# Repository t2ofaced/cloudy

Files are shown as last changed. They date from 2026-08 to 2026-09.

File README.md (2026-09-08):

# cloudy

A custom designed 60% Keyboard this keyboard is the first diy / electronic project i made from scratch, so idea was simple i wanted a keyboard so i desigined one now hopefully i can assemble it too so this keyboard use nice nano v2 clone pro micro nrf52840 development board as it give me freedom of wireless kayboard this keyboard also includes 1 enoder and 1 display and it is fully rgb thanks to SK6812MINI-E SMD leds

---

## Schematics & Circuitry

Electornic part of this Proj is desigined in KiCad 10.0

  
<br>
this is main circuitry 

<br>

  
<br>
keyswitch matrix

<br>

  
<br>
rgb chain

---

## PCB Routing & 3D View

  
<br>
routed pcb

<br>

  
<br>
3d view

---

## CAD & Case Design

Mechanical part / CAD is desigined in 4 parts 2 each for Top plate and Base plate it is in 4 parts so  that it can be printed easily
Onshape - https://cad.onshape.com/documents/02d1cc1f7ec3e59871e42e68/w/e27206701595b8be94d4fc96/e/d50220b72c1b89afdf243eaf


  
<br>
keyboard with base plate

<br>



<br>
keyboard with top plate

---

## Final Assembly



<br>
fully assembled

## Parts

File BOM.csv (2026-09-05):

Part Name | Quantity | Link | Info | Price (USD)
JLCPCB PCB Manufacturing & Shipping | 1 | https://jlcpcb.com/ | PCB | $35
0.96 inch OLED Display | 1 | https://robu.in/product/0-96-oled-display-module/ | Oled dispay | $2.35
Tactile Switches | 7 sets | https://meckeys.com/shop/accessories/keyboard-accessories/key-switches/cherry-mx-rgb-switch/ | Switches | $26.3
NiceNanoV2 | 1 | https://robu.in/product/pro-micro-nrf52840-development-board-compatible-with-nicenano-v2-0/ | mcu | $8.67
1N4148 Diodes | 70 | https://quartzcomponents.com/products/1n4148-zener-diodel | diodes | $2.22
Custom Keycaps | 1 | https://curiositycaps.in/products/comic-mixed-light-cherry-1-7mm-thick-pbt-keycaps | keycaps | $24.35
SK6812MINI-E SMD | 72 | https://www.etstore.in/products/e9974?variant=48993209319675&country=IN&currency=INR | RGBB | $9.73
LiPo Battery | 1 | https://robu.in/product/400mah-pcm-protected-micro-li-po-battery/ | 3.7V 400mAh 1S | $2.32
Disc Capacitor | 70 | https://robu.in/product/100nf-50v-disc-capacitor/ | 100nf 50v | $1
Aluminum Electrolytic Capacitors | 5 | https://robu.in/product/ers1am471e12ot-aishi-470uf-10v-%C2%B120-plugind6-3xl12mm-aluminum-electrolytic-capacitors-leaded-rohs/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 | ERS1AM471E12OT-AISHI -470uF 10V ±20% Plugin | $.5
Resistor 470 Ohms | 10 | https://www.ktron.in/product/resistor-470-ohms-0-25w-5-th/ | Resistor 470 Ohms 0.25W 5% TH | $0.2
Male Connector | 3 | https://robu.in/product/ph-aw-2mm-2-pin-wafer-male-connector-through-hole-right-angle/ | PH-AW-2mm-2 pin | $0.2
Rotary Encoder with Switch | 1 | https://robu.in/product/hongyan-ec11h-7ce20p1zd20-rotary-encoder-with-push-button-switch-vertical-plug-in-5-pin/ | EC11H 7CE20P1ZD20 5-Pin | $0.7
Slide Switch | 5 | https://robu.in/product/slide-switch-ss-12d07-1p2t/ | SS-12D07 1P2T | $0.2
Tactile Switch | 5 | https://robu.in/product/ws-a06-4-3-waterproof-tact-switch-4-pin6x6x4-3/ | 6x6x4.3mm 4 Pin | $0.2
Stabilizers | 5 | https://stackskb.com/store/durock-clear-screw-in-stabilizers-v2 | 4+1 set | $16.93
TOTAL |  |  |  | ~ $131

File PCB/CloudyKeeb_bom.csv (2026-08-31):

Designator | Footprint | Quantity | Value | LCSC Part #
C1, C10, C11, C12, C13, C14, C15, C16, C17, C18, C19, C2, C20, C21, C22, C23, C24, C25, C26, C27, C28, C29, C3, C30, C31, C32, C33, C34, C35, C36, C37, C38, C39, C4, C40, C41, C42, C43, C44, C45, C46, C47, C48, C49, C5, C50, C51, C52, C53, C54, C55, C56, C57, C58, C59, C6, C60, C61, C7, C8, C9 | C_Disc_D3.8mm_W2.6mm_P2.50mm | 61 | C
C62 | CP_Radial_D6.3mm_P2.50mm | 1 | C_Polarized_US
D100, D101, D102, D103, D104, D105, D106, D107, D108, D109, D110, D111, D112, D113, D114, D115, D116, D117, D118, D119, D120, D121, D122, D62, D63, D64, D65, D66, D67, D68, D69, D70, D71, D72, D73, D74, D75, D76, D77, D78, D79, D80, D81, D82, D83, D84, D85, D86, D87, D88, D89, D90, D91, D92, D93, D94, D95, D96, D97, D98, D99 | MX_SK6812MINI-E_REV | 61 | SK6812MINI
D123, D124, D125, D126, D127, D128, D129, D130, D131, D132, D133, D134, D135, D136, D137, D138, D139, D140, D141, D142, D143, D144, D145, D146, D147, D148, D149, D150, D151, D152, D153, D154, D155, D156, D157, D158, D159, D160, D161, D162, D163, D164, D165, D166, D167, D168, D169, D170, D171, D172, D173, D174, D175, D176, D177, D178, D179, D180, D181, D182, D183, D184 | D_DO-35_SOD27_P7.62mm_Horizontal | 62 | 1N4148
DS1 | LCD_OLED_128X64_1.3_I2C | 1 | OLED_128X64_1.3_I2C
J2 | JST_PH_S2B-PH-K_1x02_P2.00mm_Horizontal | 1 | Conn_01x02
R1 | R_Axial_DIN0207_L6.3mm_D2.5mm_P10.16mm_Horizontal | 1 | Resistor
SW1 | RotaryEncoder_Alps_EC11E-Switch_Vertical_H20mm_CircularMountingHoles | 1 | RotaryEncoder_Switch
SW100 | MX-Solderable-1U | 1 | :
SW101 | MX-Solderable-1U | 1 | "
SW102 | MX-Solderable-2.25U | 1 | Enter
SW103 | MX-Solderable-2.25U | 1 | ShiftL
SW104 | MX-Solderable-1U | 1 | Z
SW105 | MX-Solderable-1U | 1 | X
SW106 | MX-Solderable-1U | 1 | C
SW107 | MX-Solderable-1U | 1 | V
SW108 | MX-Solderable-1U | 1 | B
SW109 | MX-Solderable-1U | 1 | N
SW110 | MX-Solderable-1U | 1 | M
SW111 | MX-Solderable-1U | 1 | <
SW112 | MX-Solderable-1U | 1 | >
SW113 | MX-Solderable-1U | 1 | ?
SW114 | MX-Solderable-2.75U | 1 | ShiftR
SW115 | MX-Solderable-1.25U | 1 | CtrlL
SW116, SW120 | MX-Solderable-1.25U | 2 | Win
SW117, SW119 | MX-Solderable-1.25U | 2 | Alt
SW118 | MX-Solderable-6.25U | 1 | Space
SW121 | MX-Solderable-1.25U | 1 | Menu
SW122 | MX-Solderable-1.25U | 1 | CtrlR
SW2 | SW_PUSH_6mm_H4.3mm | 1 | SW_Push
SW3 | SW_Slide-03_Wuerth-WS-SLTV_10x2.5x6.4_P2.54mm | 1 | SW_SPDT
SW62 | MX-Solderable-1U | 1 | ~
SW63 | MX-Solderable-1U | 1 | 1
SW64 | MX-Solderable-1U | 1 | 2
SW65 | MX-Solderable-1U | 1 | 3
SW66 | MX-Solderable-1U | 1 | 4
SW67 | MX-Solderable-1U | 1 | 5
SW68 | MX-Solderable-1U | 1 | 6
SW69 | MX-Solderable-1U | 1 | 7
SW70 | MX-Solderable-1U | 1 | 8
SW71 | MX-Solderable-1U | 1 | 9
SW72 | MX-Solderable-1U | 1 | 0
SW73 | MX-Solderable-1U | 1 | -
SW74 | MX-Solderable-1U | 1 | =
SW75 | MX-Solderable-2U | 1 | Backspace
SW76 | MX-Solderable-1.5U | 1 | Tab
SW77 | MX-Solderable-1U | 1 | Q
SW78 | MX-Solderable-1U | 1 | W
SW79 | MX-Solderable-1U | 1 | E
SW80 | MX-Solderable-1U | 1 | R
SW81 | MX-Solderable-1U | 1 | T
SW82 | MX-Solderable-1U | 1 | Y
SW83 | MX-Solderable-1U | 1 | U
SW84 | MX-Solderable-1U | 1 | I
SW85 | MX-Solderable-1U | 1 | O
SW86 | MX-Solderable-1U | 1 | P
SW87 | MX-Solderable-1U | 1 | [
SW88 | MX-Solderable-1U | 1 | ]
SW89 | MX-Solderable-1.5U | 1
SW90 | MX-Solderable-1.75U | 1 | Caps Lock
SW91 | MX-Solderable-1U | 1 | A
SW92 | MX-Solderable-1U | 1 | S
SW93 | MX-Solderable-1U | 1 | D
SW94 | MX-Solderable-1U | 1 | F
SW95 | MX-Solderable-1U | 1 | G
SW96 | MX-Solderable-1U | 1 | H
SW97 | MX-Solderable-1U | 1 | J
SW98 | MX-Solderable-1U | 1 | K
SW99 | MX-Solderable-1U | 1 | L

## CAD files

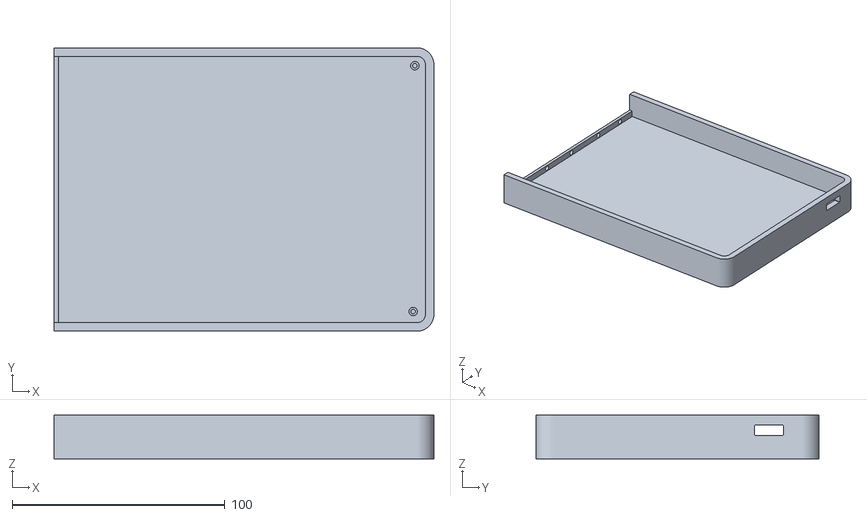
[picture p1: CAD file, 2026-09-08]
CAD/Base-B.stl
178.6 x 133.2 x 20.5

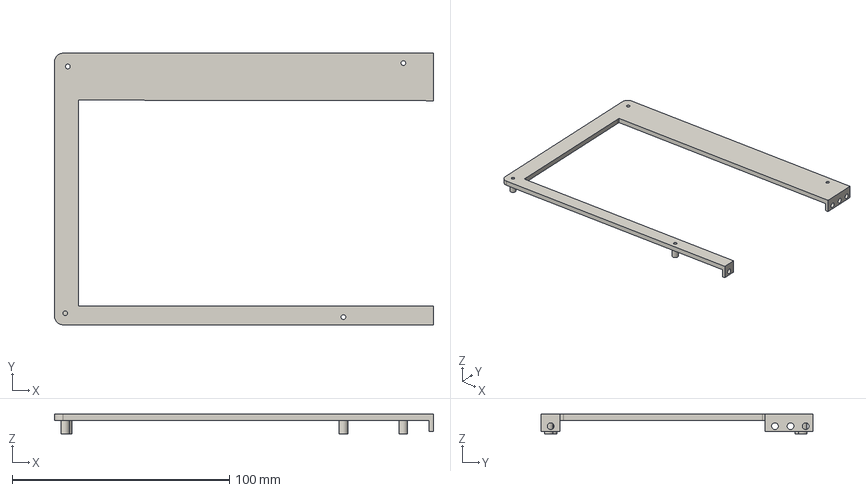
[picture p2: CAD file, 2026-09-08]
PRODUCTION FILES/CAD/Top-A.step
174.6 x 125.2 x 9.00 mm

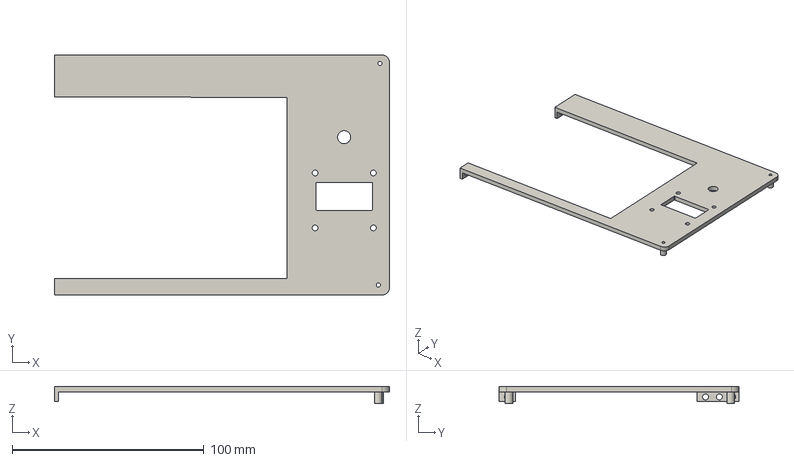
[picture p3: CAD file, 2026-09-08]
PRODUCTION FILES/CAD/Top-B.step
174.6 x 125.2 x 9.00 mm

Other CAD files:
CAD/Base-A.stl
CAD/Top-B.stl
PRODUCTION FILES/CAD/Base-B.step
CAD/Top-A.stl
PRODUCTION FILES/CAD/Base-A.step

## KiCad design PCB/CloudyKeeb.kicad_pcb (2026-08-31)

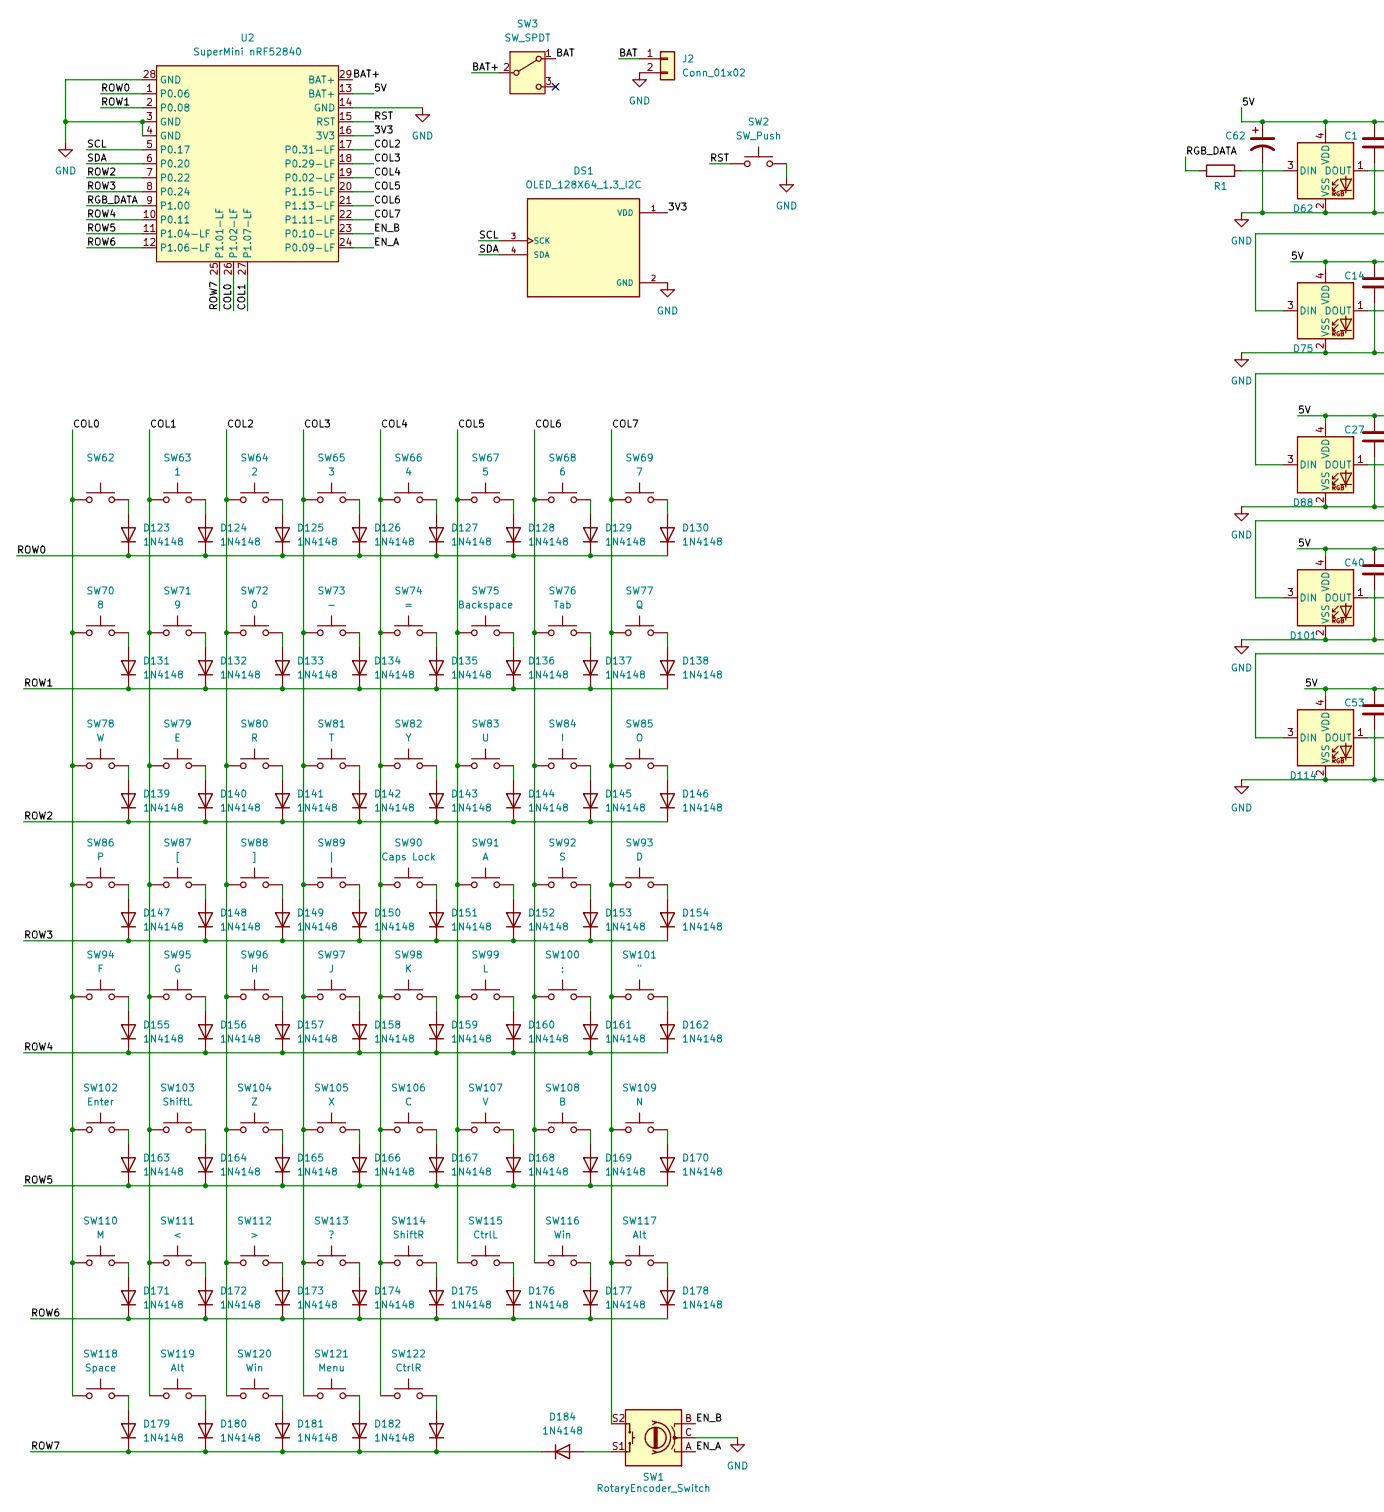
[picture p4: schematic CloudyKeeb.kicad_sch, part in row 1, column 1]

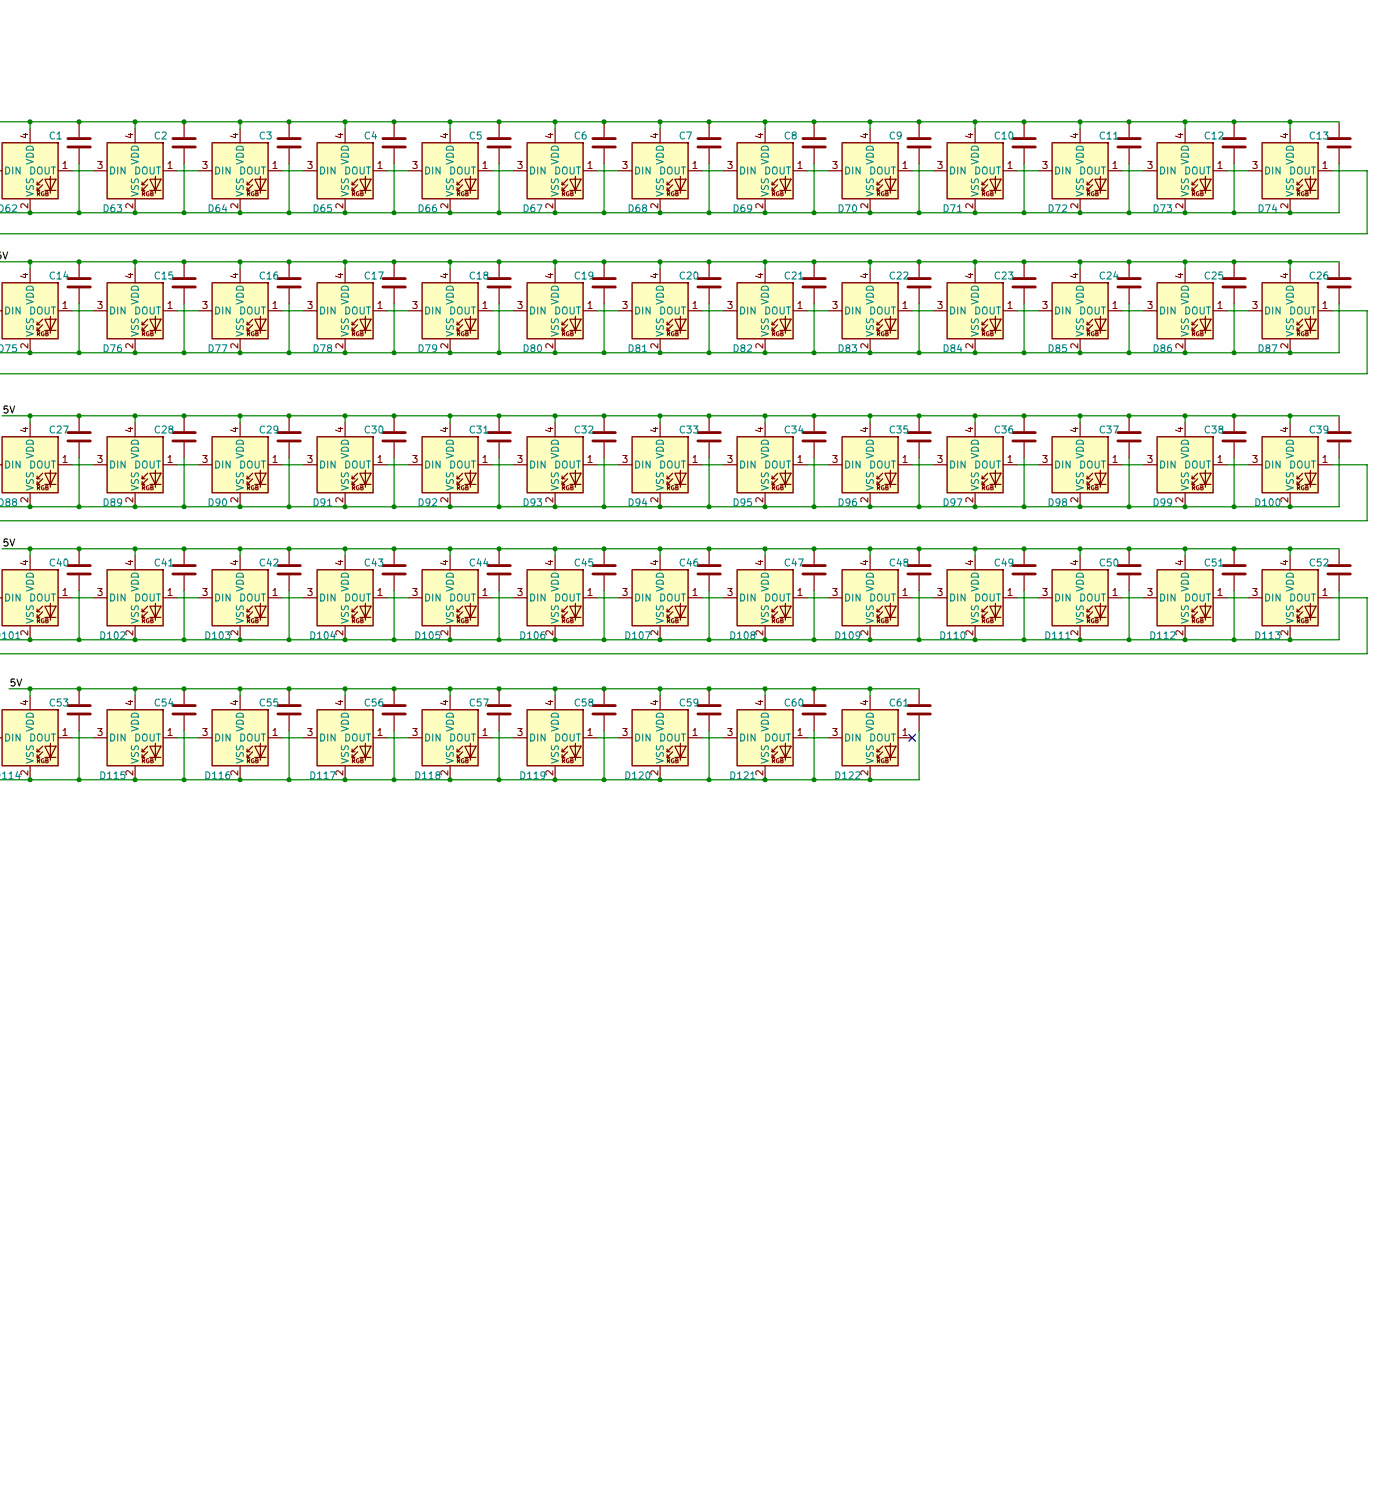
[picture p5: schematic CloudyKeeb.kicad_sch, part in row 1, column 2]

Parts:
C1, C2, C3, C4, C5, C6, C7, C8, C9, C10, C11, C12, C13, C14, C15, C16, C17, C18, C19, C20, C21, C22, C23, C24, C25, C26, C27, C28, C29, C30, C31, C32, C33, C34, C35, C36, C37, C38, C39, C40, C41, C42, C43, C44, C45, C46, C47, C48, C49, C50, C51, C52, C53, C54, C55, C56, C57, C58, C59, C60, C61: C; C_Disc_D3.8mm_W2.6mm_P2.50mm
C62: C_Polarized_US; CP_Radial_D6.3mm_P2.50mm
D62, D63, D64, D65, D66, D67, D68, D69, D70, D71, D72, D73, D74, D75, D76, D77, D78, D79, D80, D81, D82, D83, D84, D85, D86, D87, D88, D89, D90, D91, D92, D93, D94, D95, D96, D97, D98, D99, D100, D101, D102, D103, D104, D105, D106, D107, D108, D109, D110, D111, D112, D113, D114, D115, D116, D117, D118, D119, D120, D121, D122: SK6812MINI; MX_SK6812MINI-E_REV
D123, D124, D125, D126, D127, D128, D129, D130, D131, D132, D133, D134, D135, D136, D137, D138, D139, D140, D141, D142, D143, D144, D145, D146, D147, D148, D149, D150, D151, D152, D153, D154, D155, D156, D157, D158, D159, D160, D161, D162, D163, D164, D165, D166, D167, D168, D169, D170, D171, D172, D173, D174, D175, D176, D177, D178, D179, D180, D181, D182, D183, D184: 1N4148; D_DO-35_SOD27_P7.62mm_Horizontal
DS1: OLED_128X64_1.3_I2C; LCD_OLED_128X64_1.3_I2C; PARTREV NA
J2: Conn_01x02; JST_PH_S2B-PH-K_1x02_P2.00mm_Horizontal
R1: Resistor; R_Axial_DIN0207_L6.3mm_D2.5mm_P10.16mm_Horizontal
SW1: RotaryEncoder_Switch; RotaryEncoder_Alps_EC11E-Switch_Vertical_H20mm_CircularMoun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
SW2: SW_Push; SW_PUSH_6mm_H4.3mm
SW3: SW_SPDT; SW_Slide-03_Wuerth-WS-SLTV_10x2.5x6.4_P2.54mm
SW62: MX-Solderable-1U
SW63: 1; MX-Solderable-1U
SW64: 2; MX-Solderable-1U
SW65: 3; MX-Solderable-1U
SW66: 4; MX-Solderable-1U
SW67: 5; MX-Solderable-1U
SW68: 6; MX-Solderable-1U
SW69: 7; MX-Solderable-1U
SW70: 8; MX-Solderable-1U
SW71: 9; MX-Solderable-1U
SW72: 0; MX-Solderable-1U
SW73: -; MX-Solderable-1U
SW74: =; MX-Solderable-1U
SW75: Backspace; MX-Solderable-2U
SW76: Tab; MX-Solderable-1.5U
SW77: Q; MX-Solderable-1U
SW78: W; MX-Solderable-1U
SW79: E; MX-Solderable-1U
SW80: R; MX-Solderable-1U
SW81: T; MX-Solderable-1U
SW82: Y; MX-Solderable-1U
SW83: U; MX-Solderable-1U
SW84: I; MX-Solderable-1U
SW85: O; MX-Solderable-1U
SW86: P; MX-Solderable-1U
SW87: [; MX-Solderable-1U
SW88: ]; MX-Solderable-1U
SW89: |; MX-Solderable-1.5U
SW90: Caps Lock; MX-Solderable-1.75U
SW91: A; MX-Solderable-1U
SW92: S; MX-Solderable-1U
SW93: D; MX-Solderable-1U
SW94: F; MX-Solderable-1U
SW95: G; MX-Solderable-1U
SW96: H; MX-Solderable-1U
SW97: J; MX-Solderable-1U
SW98: K; MX-Solderable-1U
SW99: L; MX-Solderable-1U
SW100: :; MX-Solderable-1U
SW101: "; MX-Solderable-1U
SW102: Enter; MX-Solderable-2.25U
SW103: ShiftL; MX-Solderable-2.25U
SW104: Z; MX-Solderable-1U
SW105: X; MX-Solderable-1U
SW106: C; MX-Solderable-1U
SW107: V; MX-Solderable-1U
SW108: B; MX-Solderable-1U
SW109: N; MX-Solderable-1U
SW110: M; MX-Solderable-1U
SW111: <; MX-Solderable-1U
SW112: >; MX-Solderable-1U
SW113: ?; MX-Solderable-1U
SW114: ShiftR; MX-Solderable-2.75U
SW115: CtrlL; MX-Solderable-1.25U
SW116, SW120: Win; MX-Solderable-1.25U
SW117, SW119: Alt; MX-Solderable-1.25U
SW118: Space; MX-Solderable-6.25U
SW121: Menu; MX-Solderable-1.25U
SW122: CtrlR; MX-Solderable-1.25U
U2: SuperMini nRF52840; SuperMini NRF52840

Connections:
/3V3: DS1.1 (VDD), U2.16 (3V3)
/5V: C1.1, C2.1, C3.1, C4.1, C5.1, C6.1, C7.1, C8.1, C9.1, C10.1, C11.1, C12.1, C13.1, C14.1, C15.1, C16.1, C17.1, C18.1, C19.1, C20.1, C21.1, C22.1, C23.1, C24.1, C25.1, C26.1, C27.1, C28.1, C29.1, C30.1, C31.1, C32.1, C33.1, C34.1, C35.1, C36.1, C37.1, C38.1, C39.1, C40.1, C41.1, C42.1, C43.1, C44.1, C45.1, C46.1, C47.1, C48.1, C49.1, C50.1, C51.1, C52.1, C53.1, C54.1, C55.1, C56.1, C57.1, C58.1, C59.1, C60.1, C61.1, C62.1, D62.4 (VDD), D63.4 (VDD), D64.4 (VDD), D65.4 (VDD), D66.4 (VDD), D67.4 (VDD), D68.4 (VDD), D69.4 (VDD), D70.4 (VDD), D71.4 (VDD), D72.4 (VDD), D73.4 (VDD), D74.4 (VDD), D75.4 (VDD), D76.4 (VDD), D77.4 (VDD), D78.4 (VDD), D79.4 (VDD), D80.4 (VDD), D81.4 (VDD), D82.4 (VDD), D83.4 (VDD), D84.4 (VDD), D85.4 (VDD), D86.4 (VDD), D87.4 (VDD), D88.4 (VDD), D89.4 (VDD), D90.4 (VDD), D91.4 (VDD), D92.4 (VDD), D93.4 (VDD), D94.4 (VDD), D95.4 (VDD), D96.4 (VDD), D97.4 (VDD), D98.4 (VDD), D99.4 (VDD), D100.4 (VDD), D101.4 (VDD), D102.4 (VDD), D103.4 (VDD), D104.4 (VDD), D105.4 (VDD), D106.4 (VDD), D107.4 (VDD), D108.4 (VDD), D109.4 (VDD), D110.4 (VDD), D111.4 (VDD), D112.4 (VDD), D113.4 (VDD), D114.4 (VDD), D115.4 (VDD), D116.4 (VDD), D117.4 (VDD), D118.4 (VDD), D119.4 (VDD), D120.4 (VDD), D121.4 (VDD), D122.4 (VDD), U2.13 (BAT+)
/BAT: J2.1, SW3.1 (A)
/BAT+: SW3.2 (B), U2.29 (BAT+)
/COL0: SW62.1, SW70.1, SW78.1, SW86.1, SW94.1, SW102.1, SW110.1, SW118.1, U2.26 (P1.02-LF)
/COL1: SW63.1, SW71.1, SW79.1, SW87.1, SW95.1, SW103.1, SW111.1, SW119.1, U2.27 (P1.07-LF)
/COL2: SW64.1, SW72.1, SW80.1, SW88.1, SW96.1, SW104.1, SW112.1, SW120.1, U2.17 (P0.31-LF)
/COL3: SW65.1, SW73.1, SW81.1, SW89.1, SW97.1, SW105.1, SW113.1, SW121.1, U2.18 (P0.29-LF)
/COL4: SW66.1, SW74.1, SW82.1, SW90.1, SW98.1, SW106.1, SW114.1, SW122.1, U2.19 (P0.02-LF)
/COL5: SW67.1, SW75.1, SW83.1, SW91.1, SW99.1, SW107.1, SW115.1, U2.20 (P1.15-LF)
/COL6: SW68.1, SW76.1, SW84.1, SW92.1, SW100.1, SW108.1, SW116.1, U2.21 (P1.13-LF)
/COL7: SW1.S2, SW69.1, SW77.1, SW85.1, SW93.1, SW101.1, SW109.1, SW117.1, U2.22 (P1.11-LF)
/EN_A: SW1.A, U2.24 (P0.09-LF)
/EN_B: SW1.B, U2.23 (P0.10-LF)
/RGB_DATA: R1.1, U2.9 (P1.00)
/ROW0: D123.1 (K), D124.1 (K), D125.1 (K), D126.1 (K), D127.1 (K), D128.1 (K), D129.1 (K), D130.1 (K), U2.1 (P0.06)
/ROW1: D131.1 (K), D132.1 (K), D133.1 (K), D134.1 (K), D135.1 (K), D136.1 (K), D137.1 (K), D138.1 (K), U2.2 (P0.08)
/ROW2: D139.1 (K), D140.1 (K), D141.1 (K), D142.1 (K), D143.1 (K), D144.1 (K), D145.1 (K), D146.1 (K), U2.7 (P0.22)
/ROW3: D147.1 (K), D148.1 (K), D149.1 (K), D150.1 (K), D151.1 (K), D152.1 (K), D153.1 (K), D154.1 (K), U2.8 (P0.24)
/ROW4: D155.1 (K), D156.1 (K), D157.1 (K), D158.1 (K), D159.1 (K), D160.1 (K), D161.1 (K), D162.1 (K), U2.10 (P0.11)
/ROW5: D163.1 (K), D164.1 (K), D165.1 (K), D166.1 (K), D167.1 (K), D168.1 (K), D169.1 (K), D170.1 (K), U2.11 (P1.04-LF)
/ROW6: D171.1 (K), D172.1 (K), D173.1 (K), D174.1 (K), D175.1 (K), D176.1 (K), D177.1 (K), D178.1 (K), U2.12 (P1.06-LF)
/ROW7: D179.1 (K), D180.1 (K), D181.1 (K), D182.1 (K), D183.1 (K), D184.1 (K), U2.25 (P1.01-LF)
/RST: SW2.1, U2.15 (RST)
/SCL: DS1.3 (SCK), U2.5 (P0.17)
/SDA: DS1.4 (SDA), U2.6 (P0.20)
GND: C1.2, C2.2, C3.2, C4.2, C5.2, C6.2, C7.2, C8.2, C9.2, C10.2, C11.2, C12.2, C13.2, C14.2, C15.2, C16.2, C17.2, C18.2, C19.2, C20.2, C21.2, C22.2, C23.2, C24.2, C25.2, C26.2, C27.2, C28.2, C29.2, C30.2, C31.2, C32.2, C33.2, C34.2, C35.2, C36.2, C37.2, C38.2, C39.2, C40.2, C41.2, C42.2, C43.2, C44.2, C45.2, C46.2, C47.2, C48.2, C49.2, C50.2, C51.2, C52.2, C53.2, C54.2, C55.2, C56.2, C57.2, C58.2, C59.2, C60.2, C61.2, C62.2, D62.2 (VSS), D63.2 (VSS), D64.2 (VSS), D65.2 (VSS), D66.2 (VSS), D67.2 (VSS), D68.2 (VSS), D69.2 (VSS), D70.2 (VSS), D71.2 (VSS), D72.2 (VSS), D73.2 (VSS), D74.2 (VSS), D75.2 (VSS), D76.2 (VSS), D77.2 (VSS), D78.2 (VSS), D79.2 (VSS), D80.2 (VSS), D81.2 (VSS), D82.2 (VSS), D83.2 (VSS), D84.2 (VSS), D85.2 (VSS), D86.2 (VSS), D87.2 (VSS), D88.2 (VSS), D89.2 (VSS), D90.2 (VSS), D91.2 (VSS), D92.2 (VSS), D93.2 (VSS), D94.2 (VSS), D95.2 (VSS), D96.2 (VSS), D97.2 (VSS), D98.2 (VSS), D99.2 (VSS), D100.2 (VSS), D101.2 (VSS), D102.2 (VSS), D103.2 (VSS), D104.2 (VSS), D105.2 (VSS), D106.2 (VSS), D107.2 (VSS), D108.2 (VSS), D109.2 (VSS), D110.2 (VSS), D111.2 (VSS), D112.2 (VSS), D113.2 (VSS), D114.2 (VSS), D115.2 (VSS), D116.2 (VSS), D117.2 (VSS), D118.2 (VSS), D119.2 (VSS), D120.2 (VSS), D121.2 (VSS), D122.2 (VSS), DS1.2 (GND), J2.2, SW1.C, SW2.2, U2.3 (GND), U2.4 (GND), U2.14 (GND), U2.28 (GND)
unnamed: D62.3 (DIN), R1.2
unnamed: D62.1 (DOUT), D63.3 (DIN)
unnamed: D63.1 (DOUT), D64.3 (DIN)
unnamed: D64.1 (DOUT), D65.3 (DIN)
unnamed: D65.1 (DOUT), D66.3 (DIN)
unnamed: D66.1 (DOUT), D67.3 (DIN)
unnamed: D67.1 (DOUT), D68.3 (DIN)
unnamed: D68.1 (DOUT), D69.3 (DIN)
unnamed: D69.1 (DOUT), D70.3 (DIN)
unnamed: D70.1 (DOUT), D71.3 (DIN)
unnamed: D71.1 (DOUT), D72.3 (DIN)
unnamed: D72.1 (DOUT), D73.3 (DIN)
unnamed: D73.1 (DOUT), D74.3 (DIN)
unnamed: D74.1 (DOUT), D75.3 (DIN)
unnamed: D75.1 (DOUT), D76.3 (DIN)
unnamed: D76.1 (DOUT), D77.3 (DIN)
unnamed: D77.1 (DOUT), D78.3 (DIN)
unnamed: D78.1 (DOUT), D79.3 (DIN)
unnamed: D79.1 (DOUT), D80.3 (DIN)
unnamed: D80.1 (DOUT), D81.3 (DIN)
unnamed: D81.1 (DOUT), D82.3 (DIN)
unnamed: D82.1 (DOUT), D83.3 (DIN)
unnamed: D83.1 (DOUT), D84.3 (DIN)
unnamed: D84.1 (DOUT), D85.3 (DIN)
unnamed: D85.1 (DOUT), D86.3 (DIN)
unnamed: D86.1 (DOUT), D87.3 (DIN)
unnamed: D87.1 (DOUT), D88.3 (DIN)
unnamed: D88.1 (DOUT), D89.3 (DIN)
unnamed: D89.1 (DOUT), D90.3 (DIN)
unnamed: D90.1 (DOUT), D91.3 (DIN)
unnamed: D91.1 (DOUT), D92.3 (DIN)
unnamed: D92.1 (DOUT), D93.3 (DIN)
unnamed: D93.1 (DOUT), D94.3 (DIN)
unnamed: D94.1 (DOUT), D95.3 (DIN)
unnamed: D95.1 (DOUT), D96.3 (DIN)
unnamed: D96.1 (DOUT), D97.3 (DIN)
unnamed: D97.1 (DOUT), D98.3 (DIN)
unnamed: D98.1 (DOUT), D99.3 (DIN)
unnamed: D99.1 (DOUT), D100.3 (DIN)
unnamed: D100.1 (DOUT), D101.3 (DIN)
unnamed: D101.1 (DOUT), D102.3 (DIN)
unnamed: D102.1 (DOUT), D103.3 (DIN)
unnamed: D103.1 (DOUT), D104.3 (DIN)
unnamed: D104.1 (DOUT), D105.3 (DIN)
unnamed: D105.1 (DOUT), D106.3 (DIN)
unnamed: D106.1 (DOUT), D107.3 (DIN)
unnamed: D107.1 (DOUT), D108.3 (DIN)
unnamed: D108.1 (DOUT), D109.3 (DIN)
unnamed: D109.1 (DOUT), D110.3 (DIN)
unnamed: D110.1 (DOUT), D111.3 (DIN)
unnamed: D111.1 (DOUT), D112.3 (DIN)
unnamed: D112.1 (DOUT), D113.3 (DIN)
unnamed: D113.1 (DOUT), D114.3 (DIN)
unnamed: D114.1 (DOUT), D115.3 (DIN)
unnamed: D115.1 (DOUT), D116.3 (DIN)
unnamed: D116.1 (DOUT), D117.3 (DIN)
unnamed: D117.1 (DOUT), D118.3 (DIN)
unnamed: D118.1 (DOUT), D119.3 (DIN)
unnamed: D119.1 (DOUT), D120.3 (DIN)
unnamed: D120.1 (DOUT), D121.3 (DIN)
unnamed: D121.1 (DOUT), D122.3 (DIN)
unnamed: D123.2 (A), SW62.2
unnamed: D124.2 (A), SW63.2
unnamed: D125.2 (A), SW64.2
unnamed: D126.2 (A), SW65.2
unnamed: D127.2 (A), SW66.2
unnamed: D128.2 (A), SW67.2
unnamed: D129.2 (A), SW68.2
unnamed: D130.2 (A), SW69.2
unnamed: D131.2 (A), SW70.2
unnamed: D132.2 (A), SW71.2
unnamed: D133.2 (A), SW72.2
unnamed: D134.2 (A), SW73.2
unnamed: D135.2 (A), SW74.2
unnamed: D136.2 (A), SW75.2
unnamed: D137.2 (A), SW76.2
unnamed: D138.2 (A), SW77.2
unnamed: D139.2 (A), SW78.2
unnamed: D140.2 (A), SW79.2
unnamed: D141.2 (A), SW80.2
unnamed: D142.2 (A), SW81.2
unnamed: D143.2 (A), SW82.2
unnamed: D144.2 (A), SW83.2
unnamed: D145.2 (A), SW84.2
unnamed: D146.2 (A), SW85.2
unnamed: D147.2 (A), SW86.2
unnamed: D148.2 (A), SW87.2
unnamed: D149.2 (A), SW88.2
unnamed: D150.2 (A), SW89.2
unnamed: D151.2 (A), SW90.2
unnamed: D152.2 (A), SW91.2
unnamed: D153.2 (A), SW92.2
unnamed: D154.2 (A), SW93.2
unnamed: D155.2 (A), SW94.2
unnamed: D156.2 (A), SW95.2
unnamed: D157.2 (A), SW96.2
unnamed: D158.2 (A), SW97.2
unnamed: D159.2 (A), SW98.2
unnamed: D160.2 (A), SW99.2
unnamed: D161.2 (A), SW100.2
unnamed: D162.2 (A), SW101.2
unnamed: D163.2 (A), SW102.2
unnamed: D164.2 (A), SW103.2
unnamed: D165.2 (A), SW104.2
unnamed: D166.2 (A), SW105.2
unnamed: D167.2 (A), SW106.2
unnamed: D168.2 (A), SW107.2
unnamed: D169.2 (A), SW108.2
unnamed: D170.2 (A), SW109.2
unnamed: D171.2 (A), SW110.2
unnamed: D172.2 (A), SW111.2
unnamed: D173.2 (A), SW112.2
unnamed: D174.2 (A), SW113.2
unnamed: D175.2 (A), SW114.2
unnamed: D176.2 (A), SW115.2
unnamed: D177.2 (A), SW116.2
unnamed: D178.2 (A), SW117.2
unnamed: D179.2 (A), SW118.2
unnamed: D180.2 (A), SW119.2
unnamed: D181.2 (A), SW120.2
unnamed: D182.2 (A), SW121.2
unnamed: D183.2 (A), SW122.2
unnamed: D184.2 (A), SW1.S1

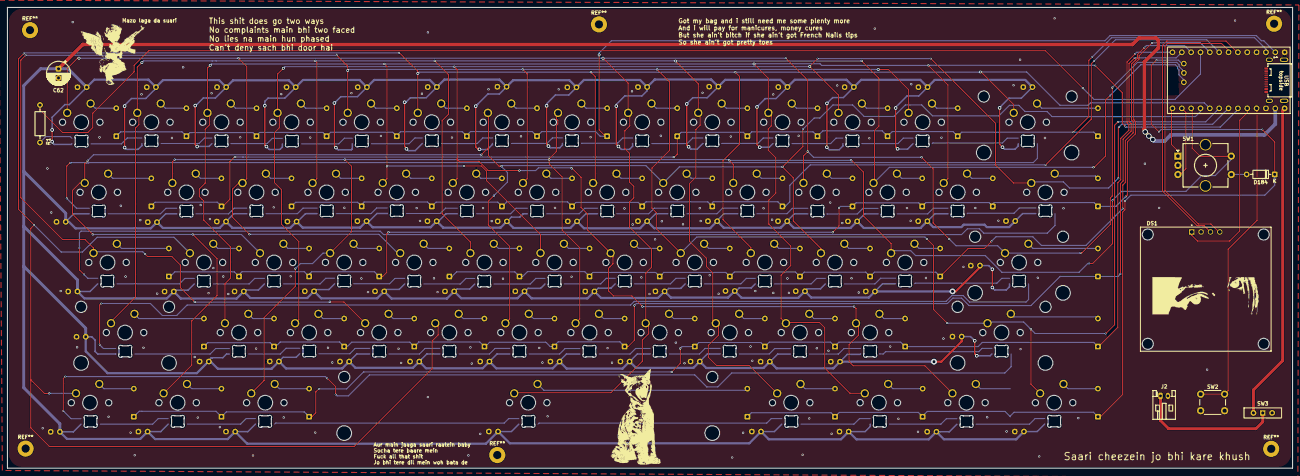
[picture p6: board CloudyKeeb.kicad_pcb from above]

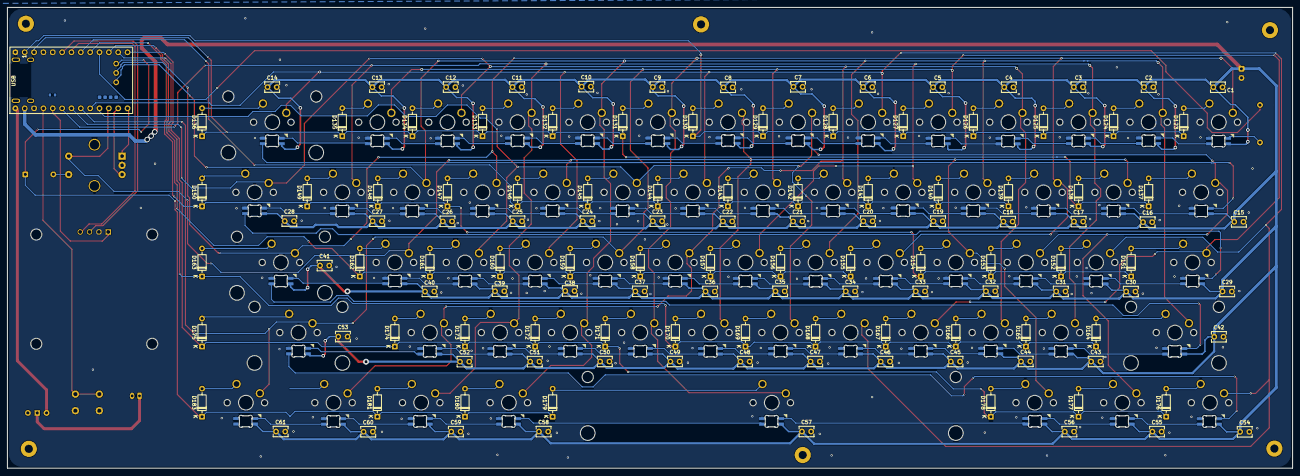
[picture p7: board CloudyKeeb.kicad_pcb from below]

Board: 2 copper layers, 349.1 x 125.2 mm, 252 parts (121 on the bottom side), 149 nets.

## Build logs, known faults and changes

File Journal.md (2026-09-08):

### 17 August 2026 | 5:00 PM - 6:00 PM (1 hr)

First of all I am really sorry for my bad english this is not my first/second language. And i do not know how this thing works all this github etc  

I want to make a 60% keyboard like thiss



but with few extra thing like e link display, encoders and extra buttons along with this 60% keyboard in short combination of keyboard and a hackpad like this





resources i used

Thought about RPI ZERO 2 W as most keyboard or hackpad i see use this but i wanted a wireless keyboard which means i need to add battery stuff charging discharging etc on pcb that will inc cost and complexity so i am using nice nano





this is soo cool

also things i want from this keyboard - wireless , rgb , e link display and encoders and few function keys like in a hackpad

### 18 August 2026 | 9:00 PM - 11:00 PM (2 hrs)

I research and i found what i am using so for keyswitches 



mx solderable 
RGB



Sk6812 mini

stared with my 14 X 5 matrix for my 60% keyboard



plce 1n4148 diodes for anti ghosting , it is to stop weird thing when press 2 key at same time this take very long time 

then leds



here i use 1 bulk capacitor and 1 ceramic capacitor with each led this one also take long time

This took around 2 hr as i placed 61 keys , capacitors , diodes and leds
ohh no when i see i need display, encoder and function btn too but now i dont have gpio pin of nice nano to connect my things i need to search about it

### 19 August 2026 | 8:00 AM - 10:00 AM (2 hrs)

After few search and findings i made my matrix small now it is 8 x 8 means 8 rows with 8 coloumns using 16 gpio pins of nice nano and oled matrix was 14 x 5 using 19 gpio pins of nice nano with no encoder so i saved 3 pin



now this is 8 x 8 and include 61 keys of keyboard and one encoder

and i still have few pins left so i add a oled display



i am trying to make a wireless keyboard so i searched for resources this is what i find this is for split keyboard but still helpfull





my connection of nice nano , olded and battry connector and on off switch

### 20 August 2026 | 9:00 AM - 11:00 AM (2 hrs)

I started component placement today and i am stuck with placing keyswitch footprint at correct place (placing keyswitches in a row or coloumn) tutorial say use grid size 19.05 but that not worked for me then i did grid size of 19.05/8 and then it worked so i placed my keyswitchs , nice nano and display



i also placed diodes on bottom side to save space on top so it is easy to wire them later



after that i placed all the capacitor and skmini led on bottom side , i started with top placement but i find out that they are bottom mounted

### 25 August 2026 | 8:00 AM - 12:00 PM (4 hrs)



thing got bad here because of my key matrix so now its hard to route



then i routed keyswitches , led capacitors with eachother and it is hard because of my 8x8 matrix so i used bottom layer for routing row, led, diodes, capacitor and resistor and routing coloumns on top layer, it is like connect two wires vertically use top layer , if horizontally use bottom layer

i will say use 14x5 matrix routing will be easy



then i connect routed nice nano with help of this





completed with jst connector for battery and a slider tu turn on and off

### 26 August 2026 | 9:00 AM - 11:00 AM (2 hrs)



SO I poured GND on my top and bottom layer





as u see a small area is left on bottom side of nice nano because of that red thing on nice nano that act as a anteena





size of my keyboard





i got this error but i think this is issue of footprint 







i read some documentation and found out we need to short rst with gnd to programe it so i do that



### 27 August 2026 | 8:00 AM - 9:00 AM (1 hr)



Added 3d modal



this have 2 pins on place of my led i think this modal internally include leds so i change this to



this is new modal



overall

then i add other thing display , nano and other modal



### 29 August 2026 | random hrs (4 hrs)



added random silkscreen quotes



then i export 3d file step of this keyboard and import in onshape so that i can desigin my encloser case around it





after imorting in onshape i make a plane just below the top plane and then using project tool make a base for pcb



i also projected walls and mounting holes on this plane by project tool and pcb 



this is base or bottom part of my keyboard with extruted mounting holes this will make pcb float 



then i added keycap modals as it was difficult to work with raw keyswitches so this is my keyboard with electronics and base



then i make a sketch above top plane according to my pcb leaving space for keycaps encoder and display 



this is top plate



top plate with pcb



whole thing together

### 1 September 2026 | 9:00 AM - 1:00 PM (4 hrs)

so i forget about type c hole in my keyboard case so i did that





then i searched about firmware first i thought i will go with zmk as it is popular and nice nano suggest this





but keeb website sugeests rmk so i searched about that too and i decided to move on with rmk



i used this rmk project template repo on github i used it as a template and made a new github repo





default config of this file
i updated it according to my config 







gave error and i debug it



some spelling error it was



so now it is completed uf2 file is actual firmware 

### 5 September 2026 | 10:30 AM - 12:00 PM (1.5 hrs)

so first i search all the component i need and made a bom.csv and put all the component and price in the bom.csv file 



and when i was searching component i found that my bulk cap need some space so i removed some part of my top plate







and then exported and updated my repo 
also made my Journal better

### 08 September 2026 | 3:00 PM - 6:00 PM (3 hrs)

So i found that my keyboard is too big to print in most common 3d printers so i sliced it in 2 parts so now i have total 4 parts 2 for top plate and 2 for base plate


This is Base-A left part of Base plate


This is Base-B right part of Base plate


This is Base plate A and B part with each other


This thing holds the A and B part with each other 


This is Top-A left part of Top plate


This is Top-A left part of Top plate


This is Top plate A and B part with each other


This thing holds the A and B part with each other 

I hope this is the final change and update in this model




afther that i reviwed PCB routing and made some high current track thick


final one more rule check and manual review and done

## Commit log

2026-08-31 Uploaded CAD files
    [Base.step, Base.stl, Top.step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]
2026-08-31 Uploaded PCB files
    [CloudyKeeb.kicad_pcb, CloudyKeeb.kicad_sch, CloudyKeeb_bom.csv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]
2026-08-31 Uploaded files required for production
    [Base.step, CloudyKeeb_bom.csv, CloudyKeeb_designators.csv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]
2026-08-31 Added updated cad files
    [Base.step, Base.stl]
2026-08-31 Added updated cad file
    [Base.step]
2026-09-05 Added Updated Top STL & STEP
    [Top.step, Top.stl]
2026-09-05 Updated Top
    [Top.step]
2026-09-08 Uploaded sliced CAD model
    [Base-A.step, Base-A.stl, Base-B.step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]
2026-10-23 Added Assembly STEP file
